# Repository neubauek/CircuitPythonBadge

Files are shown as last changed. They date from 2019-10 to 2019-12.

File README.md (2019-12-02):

# CircuitPythonBadge
Open Source Hardware Circuit Python Badge

https://kevinneubauer.com/portfolio/circuitpython-badge/

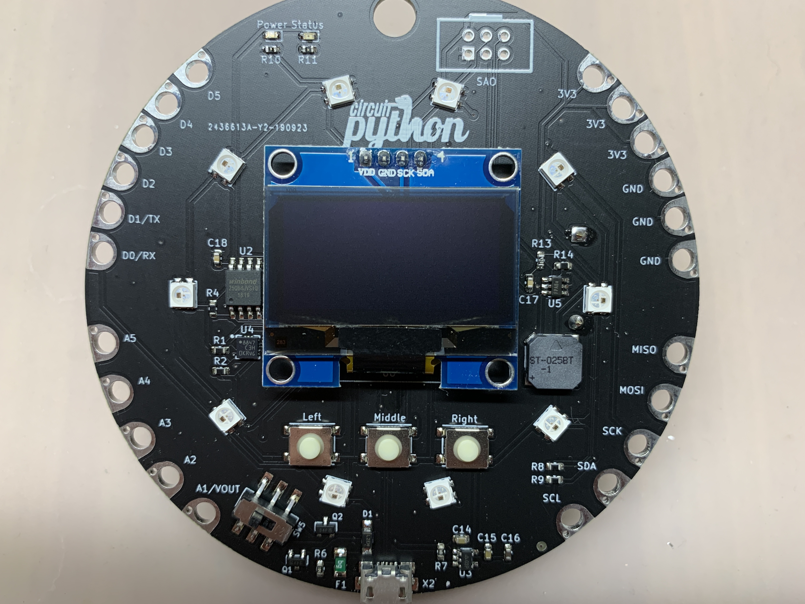
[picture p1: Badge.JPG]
Badge Image


Known Issue(s):
V1.2:
- The VDD pin on the PAM8301 chip is missing a 1 uF and a 10 uF decoupling capacitor. Without these, the speaker audio will randomly drop out. Fixed in v1.3.

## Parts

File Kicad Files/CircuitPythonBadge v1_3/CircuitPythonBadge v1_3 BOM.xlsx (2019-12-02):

Ref | Qnty | Value | Footprint | Manufacturer | Part | Vendor
BT1 | 1 |  | Keystone_2479_3xAAA | Keystone Electronics | 2479 | Digikey
C1, C2 | 2 | 13pF | 0603
C3, C9, C4, C10, C12, C11, C13, C18, C17 | 9 | 0.1uF | 0603
C5, C16 | 2 | 1uF | 0603
C6, C15, C14 | 6 | 10uF | 0603
D1 | 1 | MBR120 | SOD-123 | ON Semiconductor | MBR120ESFT1G | Arrow
F1 | 1 | 5V-500mA | 1206 | Bel Fuse Inc | 0ZCJ0025AF2E | Digikey
J1-J24 | 22 | Unpopulated | Unpopulated
L1 | 1 | 10uH | 1007 | Taiyo Yuden | CB2518T100K | Arrow
LED1 | 1 | RED | 0603
LED4 | 1 | GREEN | 0603
LED5-LED14 | 10 | SK6812 | LED3535 | Unknown | SK2812-3535 | AliExpress
Q2, Q1 | 2 | DMG341 | SOT23-R | Diodes Incorporated | DMG3415UQ-7 | Arrow
R1, R2, R3, R4, R8, R9, R14 | 5 | 10K | 0603
R5 | 1 | 330 | 0603
R6, R7 | 2 | 100K | 0603
R10, R11, R12 | 5 | 1K | 0603
R13 | 1 | 47K | 0603
SP1 | 1 | ST-025BT | BUZZER_SMT_7.5MM | Soberton | ST-025BT | Digikey
SW1 - SW4 | 4 | EVQQ2 | EVQQ2 | Panasonic | EVQ-Q2Y03W | Digikey
SW5 | 1 | JS202011SCQN | DPDT_SMT_JS202011SCQN | C&K | JS202011SCQN | Digikey
U1 | 1 | ATSAMD51J19A-AU | QFP64 | Atmel | ATSAMD51J19A-AU | Arrow
U2 | 1 | W25Q64JVSSIQ | SOIC8_208MIL | Winbond | W25Q64JVSSIQ | Digikey
U3 | 1 | AP2112K-3.3 | SOT23-DBV | Diodes Incorporated | AP2112K-3.3TRG1 | Arrow
U4 | 1 | LIS3DHTR | LGA16_3X3MM | STMicroelectronics | LIS3DHTR | Arrow
U5 | 1 | PAM8301 | SOT23-6 | Diodes Incorporated | PAM8301AAF | Arrow
U6 | 1 | SH1106_1.3"_I2C_128x64 | SH1106_1.3"_I2C_128x64 | Unknown |  | Ebay (eelectronicparts)
X1 | 1 | 2x5 0.05" SWD | 2X05_1.27MM_BOX_POSTS | CNC Tech | 3220-10-0300-00 | Digikey
X2 | 1 | 10118192-0001LF | 10118192-0001LF(MICRO-USB-B-AMPHENOL-FCI) | Amphenol ICC | 1011892-0001LF | Arrow
X3 | 1 | Badgelife_sao_connector_v169bis | Badgelife-SAOv169-BADGE-2x3 |  |  | AliExpress
Y1 | 1 | FC-135 32.7680KA-A5 | XTAL3215 | Epson | FC-135 32.7680KA-A5 | Digikey
 | 1 | PCB | PCB

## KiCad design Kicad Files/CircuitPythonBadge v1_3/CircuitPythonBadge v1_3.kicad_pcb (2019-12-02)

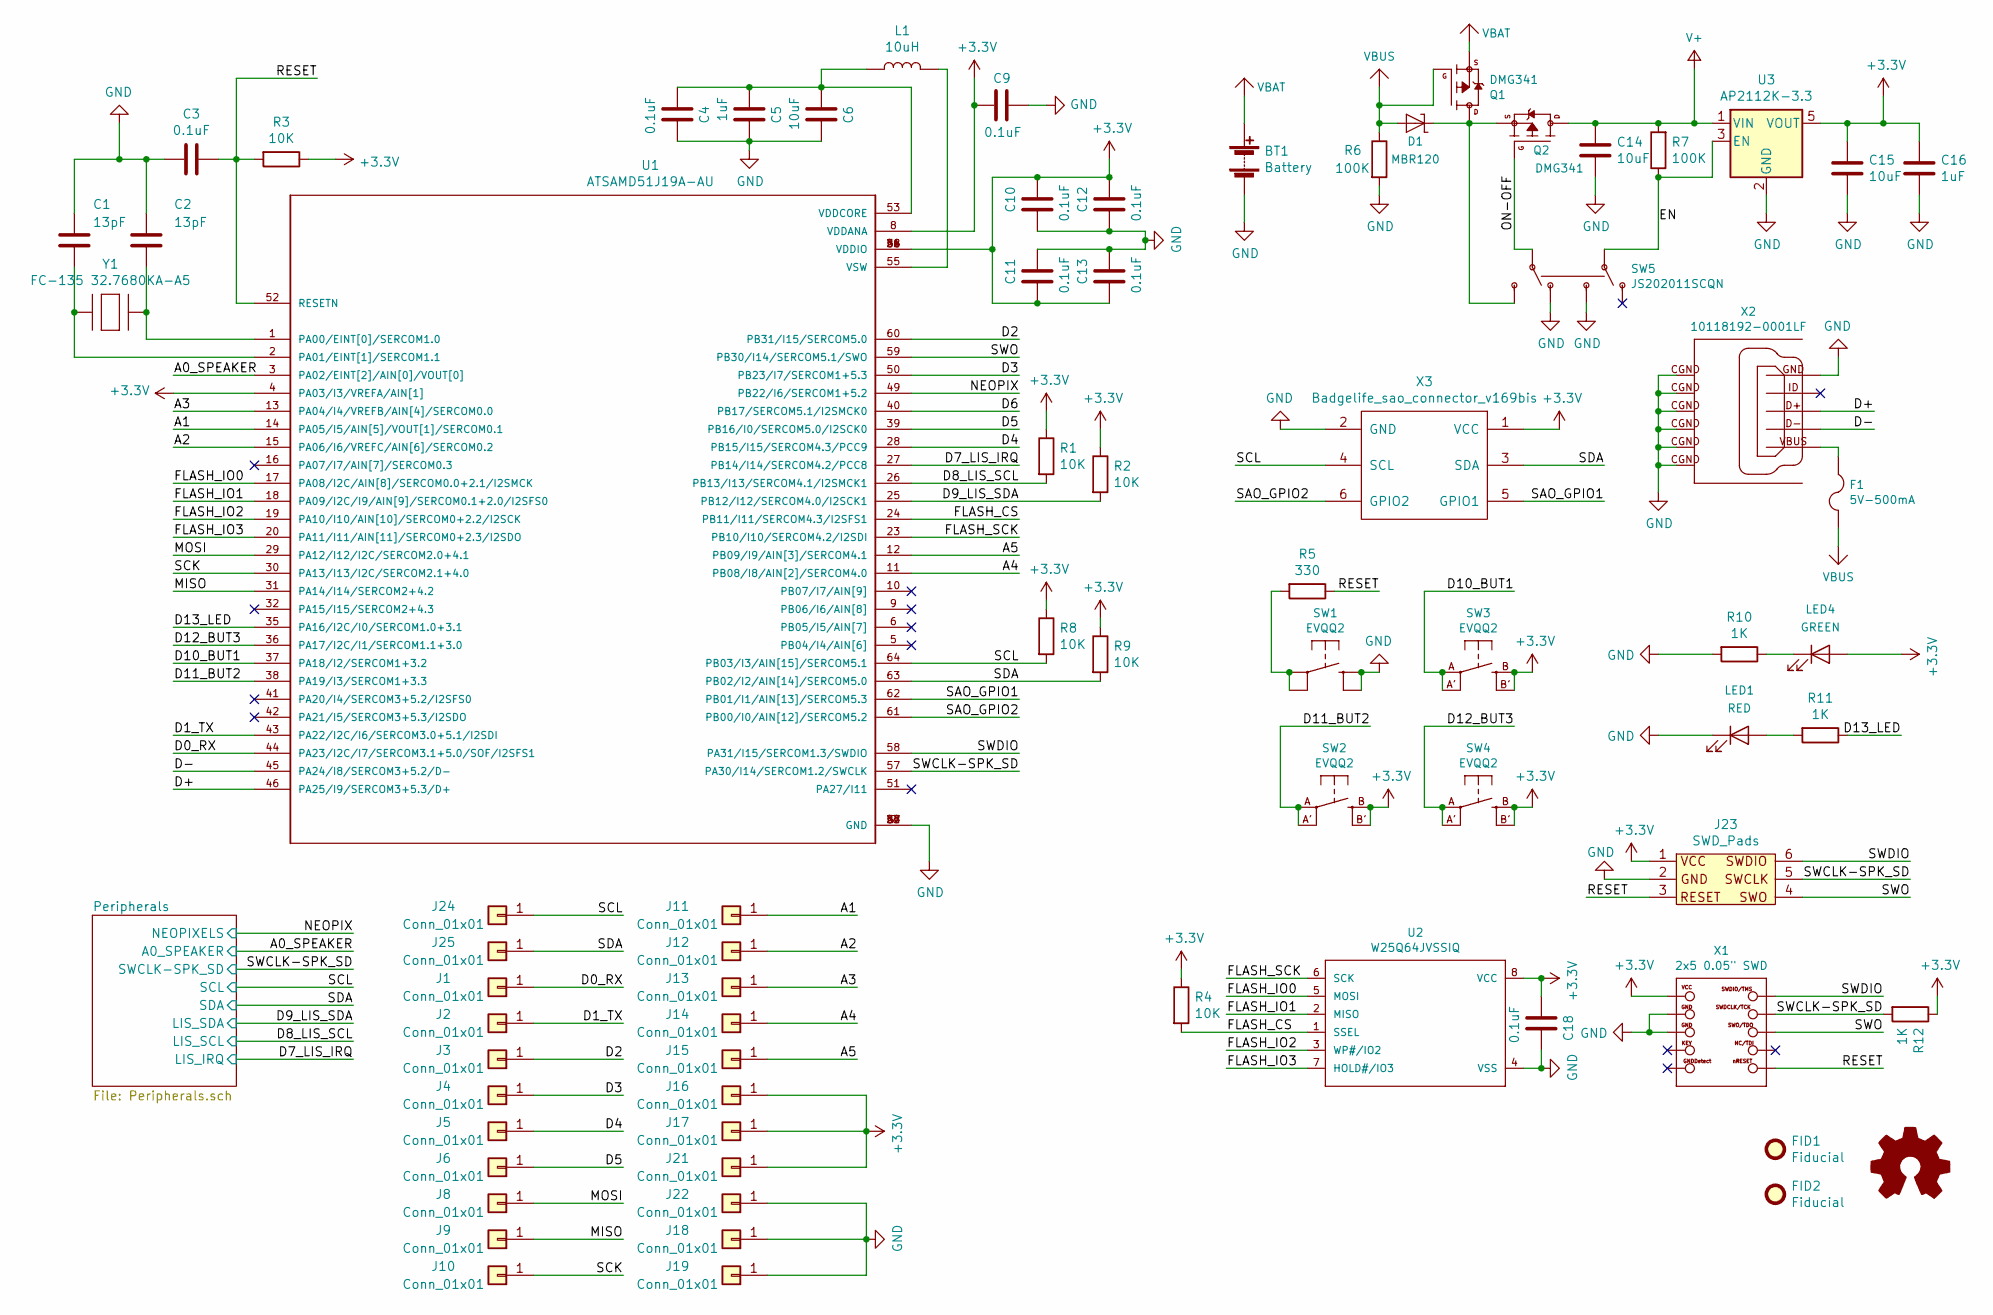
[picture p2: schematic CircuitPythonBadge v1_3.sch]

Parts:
BT1: Battery; BatteryHolder_Keystone_2464_3xAA
C1, C2: 13pF; C_0603_1608Metric
C3, C4, C9, C10, C11, C12, C13, C18: 0.1uF; C_0603_1608Metric
C5, C16: 1uF; C_0603_1608Metric
C6, C14, C15: 10uF; C_0603_1608Metric
D1: MBR120; Adafruit Hallowing M0 Express-MICROBUILDER_SOD-123
F1: 5V-500mA; Adafruit Metro M4 Express-ADAFRUIT_R1206
FID1, FID2: Fiducial; Fiducial_0.5mm_Mask1.5mm
J1, J2, J3, J4, J5, J6, J8, J9, J10, J11, J12, J13, J14, J15, J16, J17, J18, J19, J21, J22, J24, J25: Conn_01x01; SewTapSolder
J23: SWD_Pads; Pogo SWD
L1: 10uH; Adafruit Metro M4 Express-MICROBUILDER_INDUCTOR_1007
LED1: RED; LED_0603_1608Metric
LED4: GREEN; LED_0603_1608Metric
Q1, Q2: DMG341; Adafruit Hallowing M0 Express-MICROBUILDER_SOT23-R
R1, R2, R3, R4, R8, R9: 10K; R_0603_1608Metric
R5: 330; R_0603_1608Metric
R6, R7: 100K; R_0603_1608Metric
R10, R11, R12: 1K; R_0603_1608Metric
SW1, SW2, SW3, SW4: EVQQ2; Adafruit Circuit Playground Express-MICROBUILDER_EVQ-Q2_SMA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
SW5: JS202011SCQN; Adafruit Hallowing M0 Express-MICROBUILDER_DPDT_SMT_JS20201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
U1: ATSAMD51J19A-AU; QFP50P1200X1200X120-64N
U2: W25Q64JVSSIQ; SOIC8_208MIL
U3: AP2112K-3.3; Adafruit Metro M4 Express-SMARTPRJ_SOT23-DBV
X1: 2x5 0.05\" SWD; 2X05_1.27MM_BOX_POSTS
X2: 10118192-0001LF; 10118192-0001LF(MICRO-USB-B-AMPHENOL-FCI)
X3: Badgelife_sao_connector_v169bis; Badgelife-SAOv169-BADGE-2x3
Y1: FC-135 32.7680KA-A5; Adafruit Metro M4 Express-ADAFRUIT2_XTAL3215

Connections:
+3V3: C9.1, C10.2, C11.1, C12.2, C13.1, C15.1, C16.1, C18.1, J16.1, J17.1, J21.1, J23.1, LED4.2 (A), R1.1, R2.1, R3.1, R4.1, R8.1, R9.1, R12.1, SW2.B (S), SW2.B' (S1), SW3.B (S), SW3.B' (S1), SW4.B (S), SW4.B' (S1), U1.4 (PA03/I3/VREFA/AIN[1]), U1.8 (VDDANA), U1.21 (VDDIO), U1.34 (VDDIO), U1.48 (VDDIO), U1.56 (VDDIO), U2.8 (VCC), U3.5 (VOUT), X1.1 (VCC), X3.1 (VCC); also elsewhere on the board
/A0_SPEAKER: U1.3 (PA02/EINT[2]/AIN[0]/VOUT[0]); also elsewhere on the board
/A1: J11.1, U1.14 (PA05/I5/AIN[5]/VOUT[1]/SERCOM0.1)
/A2: J12.1, U1.15 (PA06/I6/VREFC/AIN[6]/SERCOM0.2)
/A3: J13.1, U1.13 (PA04/I4/VREFB/AIN[4]/SERCOM0.0)
/A4: J14.1, U1.11 (PB08/I8/AIN[2]/SERCOM4.0)
/A5: J15.1, U1.12 (PB09/I9/AIN[3]/SERCOM4.1)
/D0_RX: J1.1, U1.44 (PA23/I2C/I7/SERCOM3.1+5.0/SOF/I2SFS1)
/D1_TX: J2.1, U1.43 (PA22/I2C/I6/SERCOM3.0+5.1/I2SDI)
/D2: J3.1, U1.60 (PB31/I15/SERCOM5.0)
/D3: J4.1, U1.50 (PB23/I7/SERCOM1+5.3)
/D4: J5.1, U1.28 (PB15/I15/SERCOM4.3/PCC9)
/D5: J6.1, U1.39 (PB16/I0/SERCOM5.0/I2SCK0)
/D6: U1.40 (PB17/SERCOM5.1/I2SMCK0)
/D7_LIS_IRQ: U1.27 (PB14/I14/SERCOM4.2/PCC8); also elsewhere on the board
/D8_LIS_SCL: R1.2, U1.26 (PB13/I13/SERCOM4.1/I2SMCK1); also elsewhere on the board
/D9_LIS_SDA: R2.2, U1.25 (PB12/I12/SERCOM4.0/I2SCK1); also elsewhere on the board
/D10_BUT1: SW3.A, SW3.A' (P1), U1.37 (PA18/I2/SERCOM1+3.2)
/D11_BUT2: SW2.A, SW2.A' (P1), U1.38 (PA19/I3/SERCOM1+3.3)
/D12_BUT3: SW4.A, SW4.A' (P1), U1.36 (PA17/I2C/I1/SERCOM1.1+3.0)
/D13_LED: R11.1, U1.35 (PA16/I2C/I0/SERCOM1.0+3.1)
/D+: U1.46 (PA25/I9/SERCOM3+5.3/D+), X2.D+
/D-: U1.45 (PA24/I8/SERCOM3+5.2/D-), X2.D-
/EN: R7.1, SW5.P$2 (P1), U3.3 (EN)
/FLASH_CS: R4.2, U1.24 (PB11/I11/SERCOM4.3/I2SFS1), U2.1 (SSEL)
/FLASH_IO0: U1.17 (PA08/I2C/AIN[8]/SERCOM0.0+2.1/I2SMCK), U2.5 (MOSI)
/FLASH_IO1: U1.18 (PA09/I2C/I9/AIN[9]/SERCOM0.1+2.0/I2SFS0), U2.2 (MISO)
/FLASH_IO2: U1.19 (PA10/I10/AIN[10]/SERCOM0+2.2/I2SCK), U2.3 (WP#/IO2)
/FLASH_IO3: U1.20 (PA11/I11/AIN[11]/SERCOM0+2.3/I2SDO), U2.7 (HOLD#/IO3)
/FLASH_SCK: U1.23 (PB10/I10/SERCOM4.2/I2SDI), U2.6 (SCK)
/MISO: J9.1, U1.31 (PA14/I14/SERCOM2+4.2)
/MOSI: J8.1, U1.29 (PA12/I12/I2C/SERCOM2.0+4.1)
/NEOPIX: U1.49 (PB22/I6/SERCOM1+5.2); also elsewhere on the board
/ON-OFF: Q2.1 (G), SW5.P$5 (P2)
/RESET: C3.1, J23.3, R3.2, R5.1, U1.52 (RESETN), X1.10 (NRESET); also elsewhere on the board
/SAO_GPIO1: U1.62 (PB01/I1/AIN[13]/SERCOM5.3), X3.5 (GPIO1)
/SAO_GPIO2: U1.61 (PB00/I0/AIN[12]/SERCOM5.2), X3.6 (GPIO2)
/SCK: J10.1, U1.30 (PA13/I13/I2C/SERCOM2.1+4.0)
/SCL: J24.1, R8.2, U1.64 (PB03/I3/AIN[15]/SERCOM5.1), X3.4 (SCL)
/SDA: J25.1, R9.2, U1.63 (PB02/I2/AIN[14]/SERCOM5.0), X3.3 (SDA)
/SWCLK-SPK_SD: J23.5, R12.2, U1.57 (PA30/I14/SERCOM1.2/SWCLK), X1.4 (SWDCLK); also elsewhere on the board
/SWO: J23.4, U1.59 (PB30/I14/SERCOM5.1/SWO), X1.6 (SWO); also elsewhere on the board
unnamed: C1.2, U1.2 (PA01/EINT[1]/SERCOM1.1), Y1.P$1
unnamed: C2.2, U1.1 (PA00/EINT[0]/SERCOM1.0), Y1.P$2
unnamed: C4.1, C5.1, C6.1, L1.P$1 (1), U1.53 (VDDCORE)
unnamed: D1.C, Q1.3 (D), Q2.2 (S), SW5.P$4 (S2)
unnamed: F1.1, X2.VBUS
unnamed: L1.P$2 (2), U1.55 (VSW)
unnamed: LED1.2 (A), R11.2
unnamed: LED4.1 (K), R10.1
unnamed: R5.2, SW1.A, SW1.A' (P1)
V+: C14.1, Q2.3 (D), R7.2, U3.1 (VIN); also elsewhere on the board
VBAT: BT1.1 (+), Q1.2 (S)
VBUS: D1.A, F1.2, Q1.1 (G), R6.1

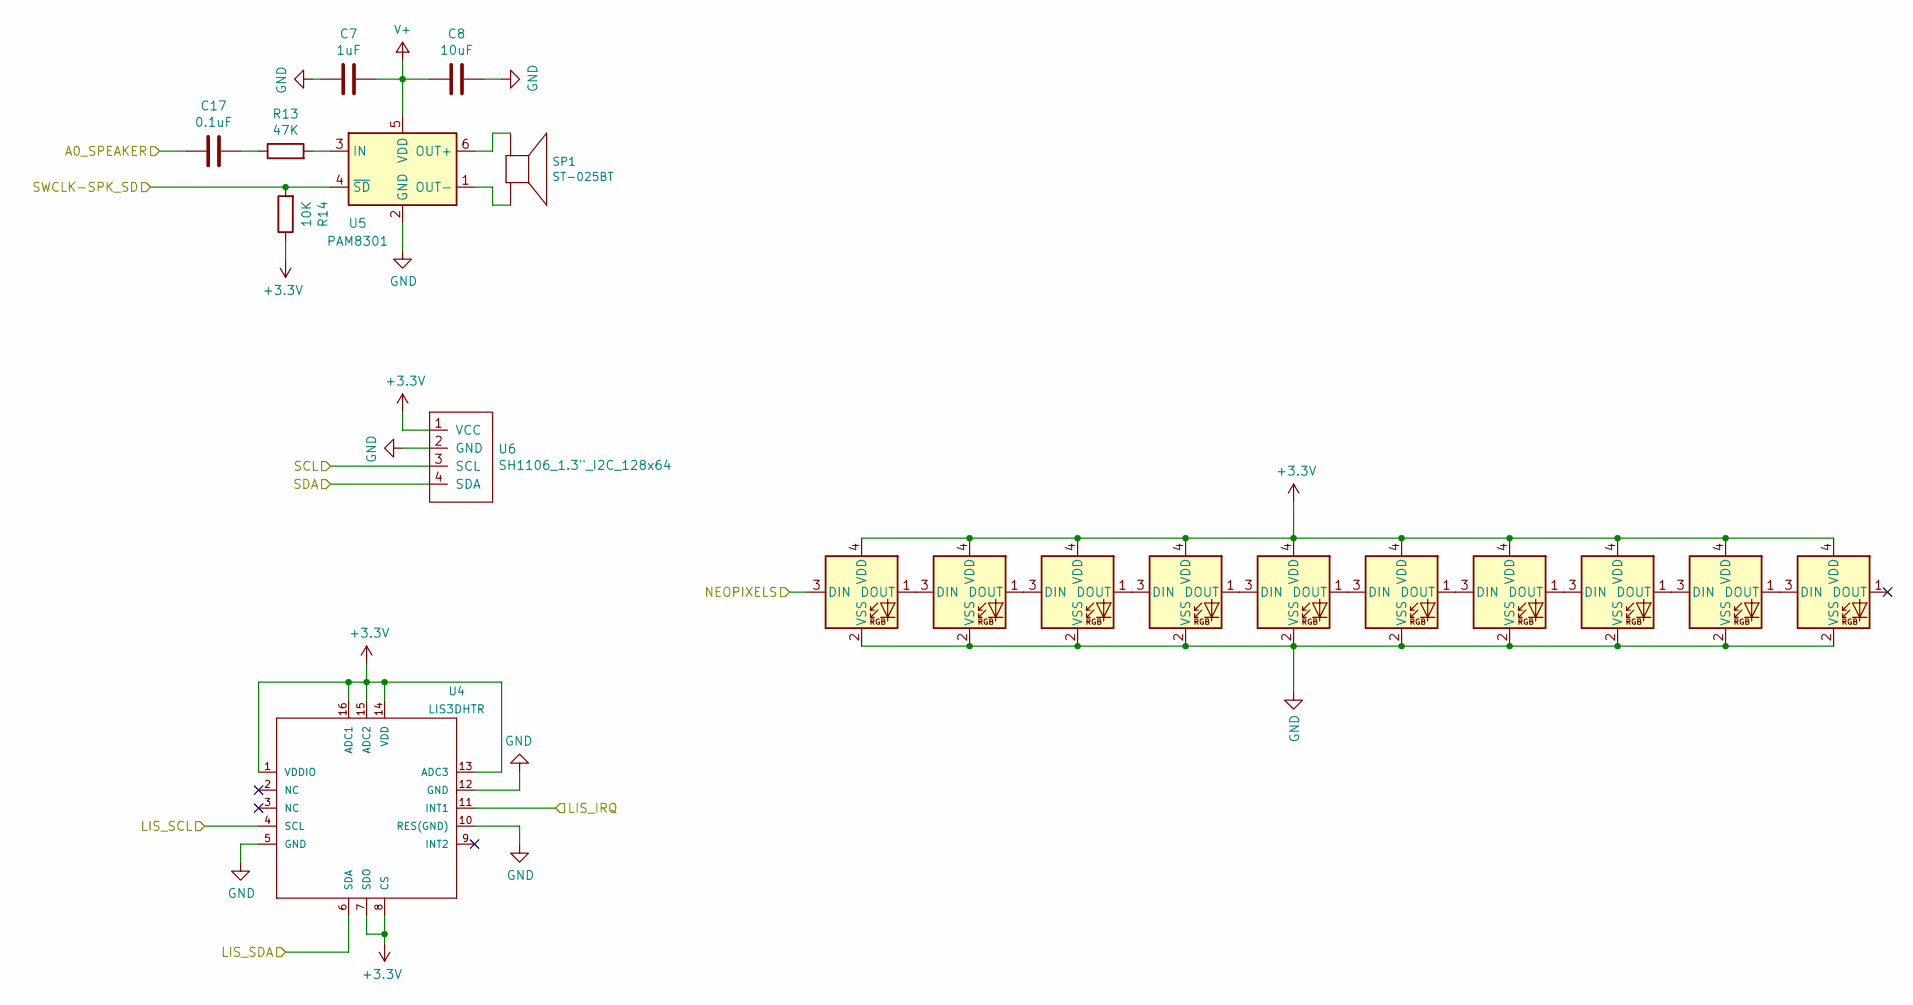
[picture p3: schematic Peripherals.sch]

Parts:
C7: 1uF; C_0603_1608Metric
C8: 10uF; C_0603_1608Metric
C17: 0.1uF; C_0603_1608Metric
LED5, LED6, LED7, LED8, LED9, LED10, LED11, LED12, LED13, LED14: SK6812; SK6812_Mini
R13: 47K; R_0603_1608Metric
R14: 10K; R_0603_1608Metric
SP1: ST-025BT; BUZZER_SMT_7.5MM
U4: LIS3DHTR; Adafruit Circuit Playground Express-MICROBUILDER_LGA16_3X3MM
U5: PAM8301; Adafruit Circuit Playground Express-MICROBUILDER_SOT23-6
U6: SH1106_1.3\"_I2C_128x64; SH1106_1.3_I2C_128x64

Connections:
+3V3: LED5.4 (VDD), LED6.4 (VDD), LED7.4 (VDD), LED8.4 (VDD), LED9.4 (VDD), LED10.4 (VDD), LED11.4 (VDD), LED12.4 (VDD), LED13.4 (VDD), LED14.4 (VDD), R14.1, U4.1 (VDDIO), U4.7 (SDO), U4.8 (CS), U4.13 (ADC3), U4.14 (VDD), U4.15 (ADC2), U4.16 (ADC1), U6.1 (VCC); also elsewhere on the board
/A0_SPEAKER: C17.2; also elsewhere on the board
/D7_LIS_IRQ: U4.11 (INT1); also elsewhere on the board
/D8_LIS_SCL: U4.4 (SCL); also elsewhere on the board
/D9_LIS_SDA: U4.6 (SDA); also elsewhere on the board
/NEOPIX: LED5.3 (DIN); also elsewhere on the board
/RESET: U6.10; also elsewhere on the board
/SWCLK-SPK_SD: R14.2, U5.4 (~SD), U6.4 (SDA); also elsewhere on the board
/SWO: U6.6; also elsewhere on the board
unnamed: C17.1, R13.1
unnamed: LED5.1 (DOUT), LED7.3 (DIN)
unnamed: LED6.1 (DOUT), LED8.3 (DIN)
unnamed: LED7.1 (DOUT), LED9.3 (DIN)
unnamed: LED10.1 (DOUT), LED12.3 (DIN)
unnamed: LED8.1 (DOUT), LED10.3 (DIN)
unnamed: LED11.1 (DOUT), LED13.3 (DIN)
unnamed: LED9.1 (DOUT), LED11.3 (DIN)
unnamed: LED12.1 (DOUT), LED14.3 (DIN)
unnamed: LED6.3 (DIN), LED13.1 (DOUT)
unnamed: R13.2, U5.3 (IN)
unnamed: SP1.+, U5.6 (OUT+)
unnamed: SP1.-, U5.1 (OUT-)
V+: C7.1, C8.2, U5.5 (VDD); also elsewhere on the board

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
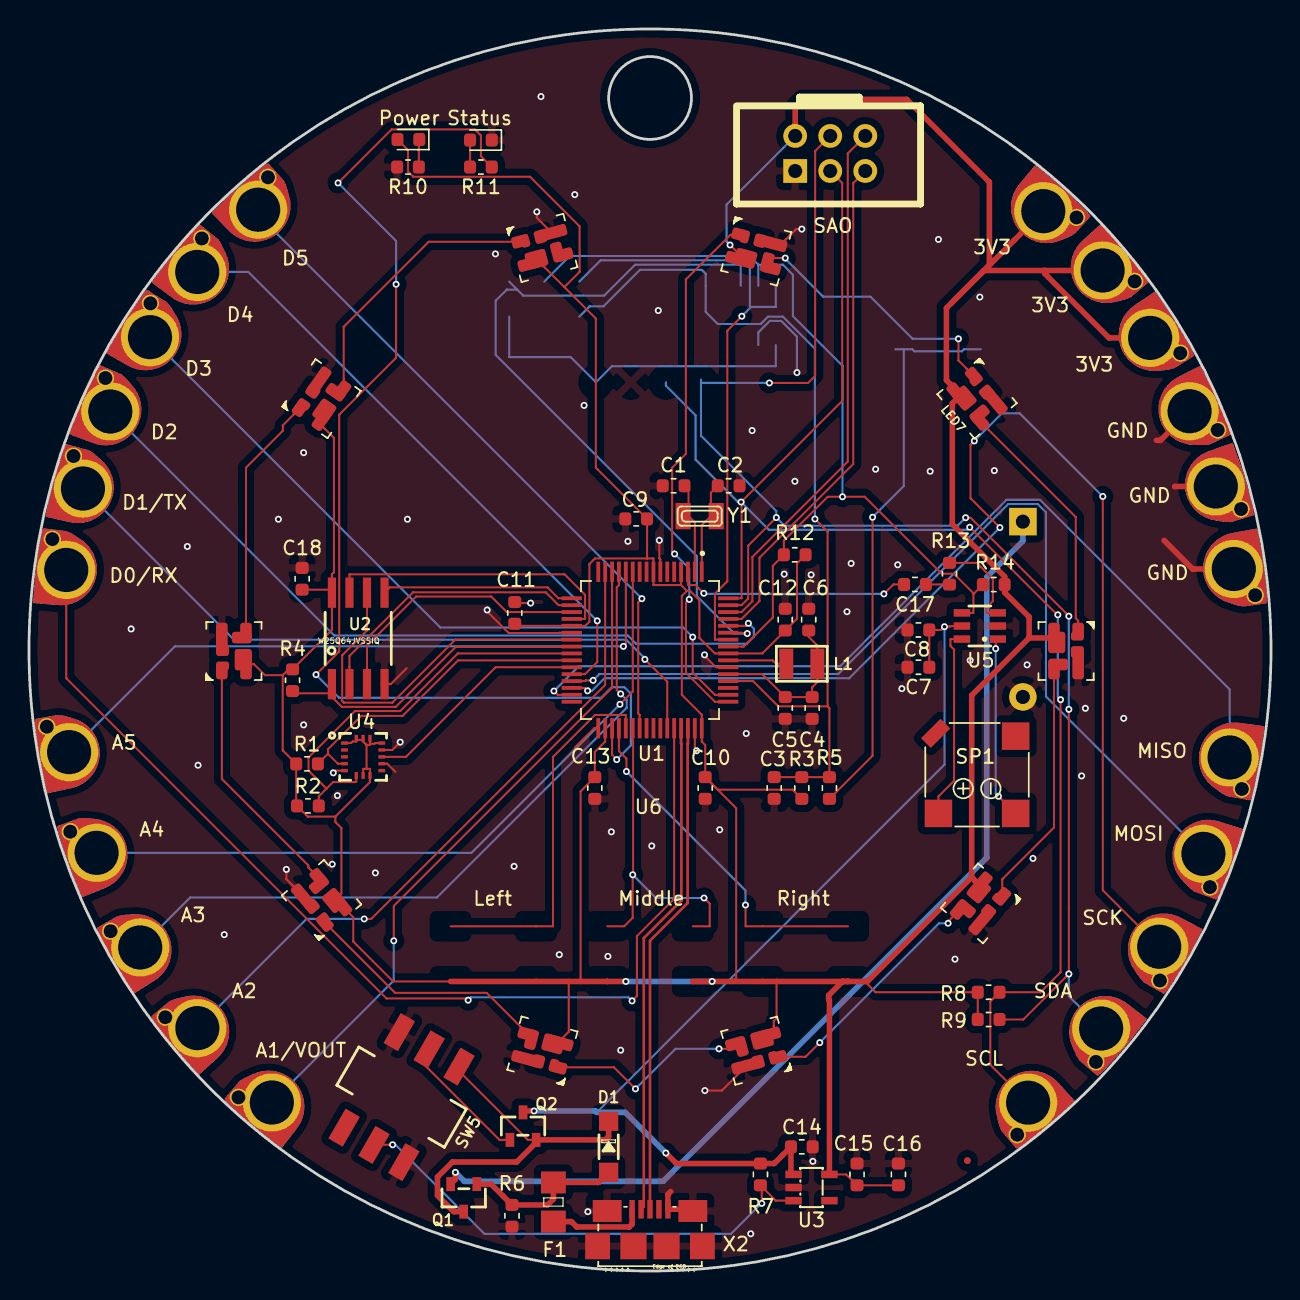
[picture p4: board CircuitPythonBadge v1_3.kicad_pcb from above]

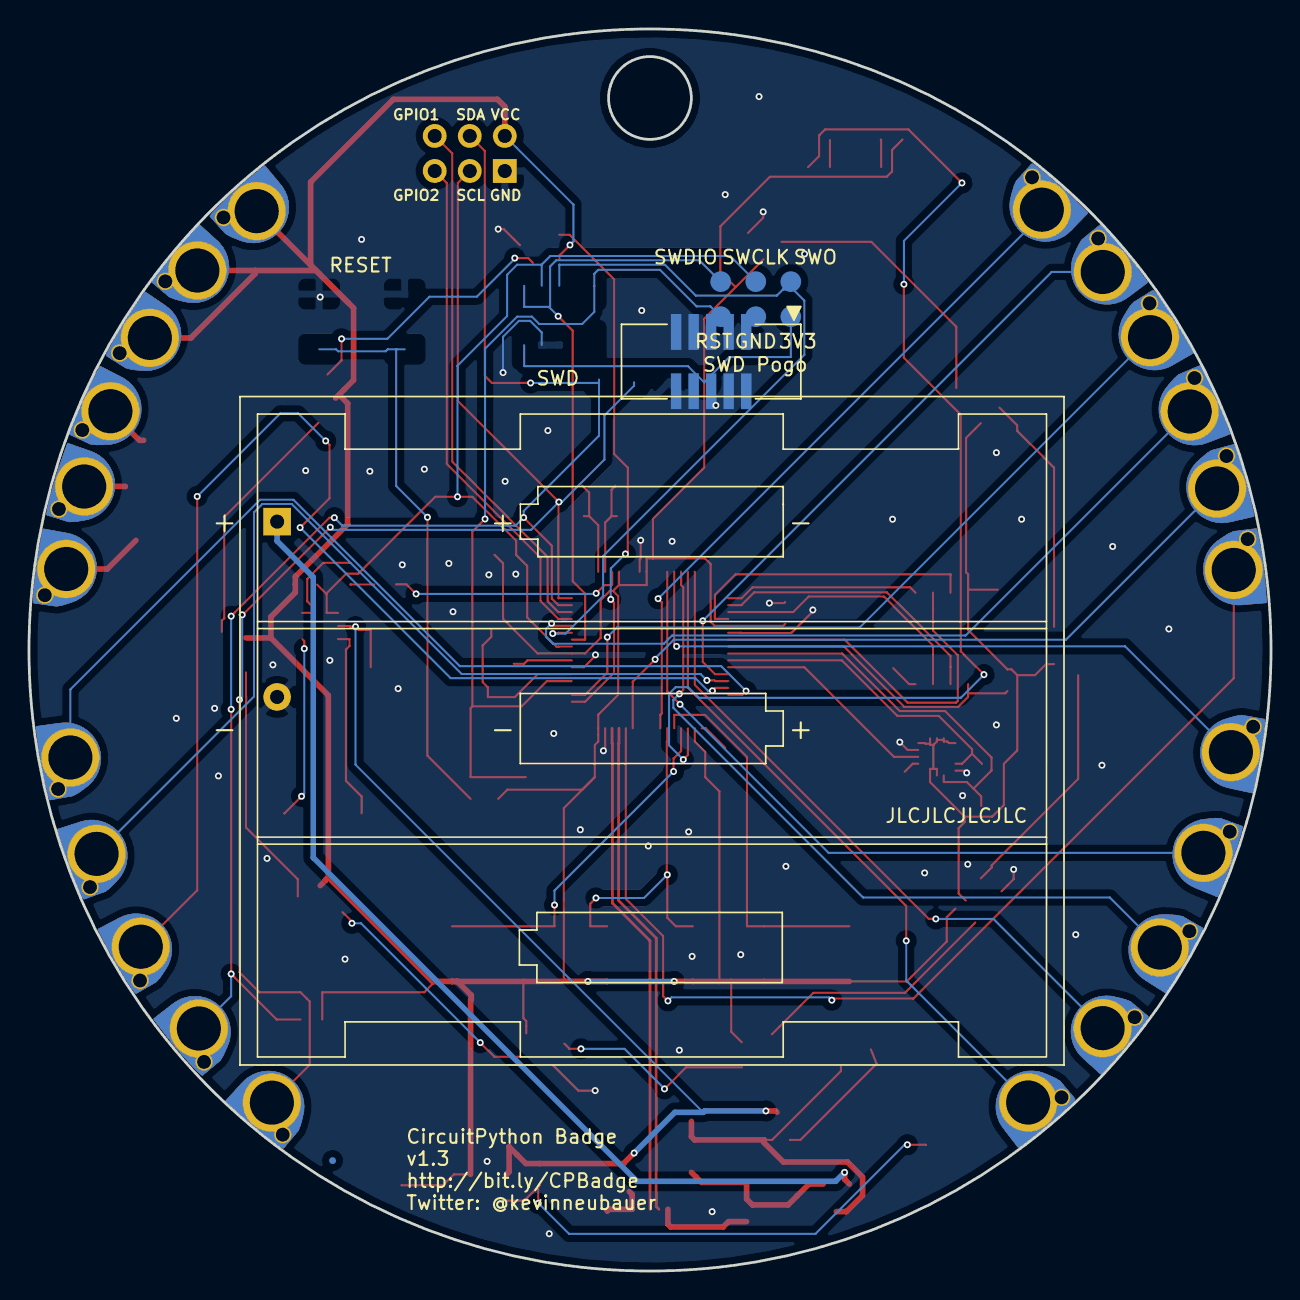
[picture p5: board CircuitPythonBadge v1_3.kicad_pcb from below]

Board: 2 copper layers, 90.0 x 90.0 mm, 86 parts (3 on the bottom side), 64 nets.

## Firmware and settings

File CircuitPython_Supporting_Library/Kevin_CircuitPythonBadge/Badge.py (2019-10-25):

# The MIT License (MIT)
#
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
# We have a lot of attributes for this complex library.
# pylint: disable=too-many-instance-attributes

"""
`Kevin_CircyitPythonBadge.Badge`
====================================================

CircuitPython driver for Kevin Neubauer's Circuit Python Badge _.
Adapted from Circuit Playground Express driver _.
* Circuit Playground Express Author(s): Kattni Rembor, Scott Shawcroft
"""

import array
import math
import sys
import time
# pylint: disable=wrong-import-position
try:
    lib_index = sys.path.index("/lib")        # pylint: disable=invalid-name
    if lib_index < sys.path.index(".frozen"):
        # Prefer frozen modules over those in /lib.
        sys.path.insert(lib_index, ".frozen")
except ValueError:
    # Don't change sys.path if it doesn't contain "lib" or ".frozen".
    pass

import adafruit_lis3dh
import analogio
import audioio
try:
    import audiocore
except ImportError:
    audiocore = audioio
import board
import busio
import digitalio
import neopixel
import touchio

__version__ = "1.0.0"
__repo__ = ""


class Badge:     # pylint: disable=too-many-public-methods
    """Represents a single CircuitPython Badge. Do not use more than one at
       a time."""
    def __init__(self):
        # Only create the Badge module member when we're aren't being imported by Sphinx
        if ("__module__" in dir(digitalio.DigitalInOut) and
                digitalio.DigitalInOut.__module__ == "sphinx.ext.autodoc"):
            return
        self._left = digitalio.DigitalInOut(board.LEFT_BUTTON)
        self._left.switch_to_input(pull=digitalio.Pull.DOWN)
        self._middle = digitalio.DigitalInOut(board.MIDDLE_BUTTON)
        self._middle.switch_to_input(pull=digitalio.Pull.DOWN)
        self._right = digitalio.DigitalInOut(board.RIGHT_BUTTON)
        self._right.switch_to_input(pull=digitalio.Pull.DOWN)

        # Define LEDs:
        self._led = digitalio.DigitalInOut(board.STATUS_LED)
        self._led.switch_to_output()
        self._pixels = neopixel.NeoPixel(board.NEOPIXEL, 10)

        # Define audio:
        self._speaker_enable = digitalio.DigitalInOut(board.SPEAKER_ENABLE)
        self._speaker_enable.switch_to_output(value=False)
        self._sample = None
        self._sine_wave = None
        self._sine_wave_sample = None

        # Define touch:
        # Initially, self._touches stores the pin used for a particular touch. When that touch is
        # used for the first time, the pin is replaced with the corresponding TouchIn object.
        # This saves a little RAM over using a separate read-only pin tuple.
        # For example, after `Badge.touch_A2`, self._touches is equivalent to:
        # [None, board.A1, touchio.TouchIn(board.A2), board.A3, ...]
        # Slot 0 is not used (A0 is not allowed as a touch pin).
        self._touches = [None, board.A1, board.A2, board.A3, board.A4, board.A5]
        self._touch_threshold_adjustment = 0

        # Define acceleration:
        self._i2c = busio.I2C(board.ACCELEROMETER_SCL, board.ACCELEROMETER_SDA)
        self._int1 = digitalio.DigitalInOut(board.ACCELEROMETER_INTERRUPT)
        self._lis3dh = adafruit_lis3dh.LIS3DH_I2C(self._i2c, address=0x19, int1=self._int1)
        self._lis3dh.range = adafruit_lis3dh.RANGE_8_G

        # Initialise tap:
        self._detect_taps = 1
        self.detect_taps = 1

    @property
    def detect_taps(self):
        """Configure what type of tap is detected by ``cpx.tapped``. Use ``1`` for single-tap
        detection and ``2`` for double-tap detection. This does nothing without ``cpx.tapped``.

        .. image :: ../docs/_static/accelerometer.jpg
          :alt: Accelerometer

        .. code-block:: python

          from adafruit_circuitplayground.express import cpx

          cpx.detect_taps = 1
          while True:
            if cpx.tapped:
              print("Single tap detected!")
        """
        return self._detect_taps

    @detect_taps.setter
    def detect_taps(self, value):
        self._detect_taps = value
        if value == 1:
            self._lis3dh.set_tap(value, 90, time_limit=4, time_latency=50, time_window=255)
        if value == 2:
            self._lis3dh.set_tap(value, 60, time_limit=10, time_latency=50, time_window=255)

    @property
    def tapped(self):
        """True once after a detecting a tap. Requires ``cpx.detect_taps``.

        .. image :: ../docs/_static/accelerometer.jpg
          :alt: Accelerometer

        Tap the CPX once for a single-tap, or quickly tap twice for a double-tap.

        .. code-block:: python

          from adafruit_circuitplayground.express import cpx

          cpx.detect_taps = 1

          while True:
              if cpx.tapped:
                  print("Single tap detected!")

        To use single and double tap together, you must have a delay between them. It
        will not function properly without it. This example uses both by counting a
        specified number of each type of tap before moving on in the code.

        .. code-block:: python

          from adafruit_circuitplayground.express import cpx

          # Set to check for single-taps.
          cpx.detect_taps = 1
          tap_count = 0

          # We're looking for 2 single-taps before moving on.
          while tap_count < 2:
              if cpx.tapped:
                  tap_count += 1
          print("Reached 2 single-taps!")

          # Now switch to checking for double-taps
          tap_count = 0
          cpx.detect_taps = 2

          # We're looking for 2 double-taps before moving on.
          while tap_count < 2:
              if cpx.tapped:
                 tap_count += 1
          print("Reached 2 double-taps!")
          print("Done.")

        """
        return self._lis3dh.tapped

    @property
    def acceleration(self):
        """Obtain data from the x, y and z axes.

        .. image :: ../docs/_static/accelerometer.jpg
          :alt: Accelerometer

        This example prints the values. Try moving the board to see how the
        printed values change.

        .. code-block:: python

          from adafruit_circuitplayground.express import cpx

          while True:
              x, y, z = cpx.acceleration
              print(x, y, z)
        """
        return self._lis3dh.acceleration

    def shake(self, shake_threshold=30):
        """Detect when device is shaken.

        :param int shake_threshold: The threshold shake must exceed to return true (Default: 30)

        .. image :: ../docs/_static/accelerometer.jpg
          :alt: Accelerometer

        .. code-block:: python

          from adafruit_circuitplayground.express import cpx

          while True:
              if cpx.shake():
                  print("Shake detected!")
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
